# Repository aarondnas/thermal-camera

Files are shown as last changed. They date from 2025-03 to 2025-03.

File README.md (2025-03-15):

# Gesundheitstechnik Gruppenprojekt

In diesem Projekt wird ein Prototyp für einen Thermographen (Wärmebildkamera) entwickelt.

## Inhaltsverzeichnis
1. [Beschreibung](#beschreibung)
2. [Anforderungen an die Entwicklungsumgebung](#anforderungen-an-die-entwicklungsumgebung)
3. [Verwendete Libraries](#verwendete-libraries)
4. [Setup und Installation](#setup-und-installation)
    - [Software](#software)
        - [Installation Raspberry Pi OS](#installation-raspberrypi-os)
        - [Terminal Installationen](#terminal-installationen)
        - [Implementierung von Code aus Repository](#)
    - [Hardware](#hardware)
        - [CAD - Setup und Installation](#cad)
    - [Elektronik](#elektronik)
        - [Bauteile](#bauteile)
5. [Support](#support)

## Beschreibung
Teil des Projekts ist die Entwicklung der Software, der Elektrotechnik und der Konstruktion.

Wichtigste Funktionen:
- Erkennung des zu messenden Körperteils
- ein Körperteil einrahmen und fixieren
- Verschiedene Filtermodi zur Temperaturmessung zwischen 36 und 39° Celsius
- Bedienoberfläche
- Schnappschussfunktion durch digitalen Trigger und Abspeichern des Bildes

## Anforderungen an die Entwicklungsumgebung
[Python 3.x](https://www.python.org/downloads/)

## Verwendete Libraries
- tkinter 
- from tkinter import *
- cv2
- customtkinter
- from operator import mil
- import lumpy as np
- from PIL import Image, ImageDraw, Imagefilter, ImageTK
- datetime

## Verwendete IDE
Visual Studio Code Version: 1.72.1 (Universal)

## Setup und Installation
### Software
#### Installation Raspberry Pi OS auf Micro-SD
Installiere mit dem [Raspberry Pi Imager](https://www.raspberrypi.com/software/) das Betriebssystem für den Raspberry Pi 3b v. 1.2 um anschließend folgende Imports über das Terminal zu installieren.

#### Terminal Installationen:
1. Installieren der Libraries:

Für Ubuntu: 
```
sudo apt-get install python3-tk
sudo apt-get install libopencv-dev
```

#### Implementierung von Code aus Repository
Um den gesamten Code ordnungsgemäß nutzen zu können, downloade [hier](https://gitlab.rz.htw-berlin.de/s0577479/gesundheitstechnik_thermograph/-/archive/main/gesundheitstechnik_thermograph-main.zip) die .zip Datei um ihn anschließend auf dem Raspberry Pi auszuführen. 

### Hardware
#### CAD
Der erste Prototyp für das Gehaeuse wurde mit AutoDesk 360 entworfen. Im Ordner [Gehaeuse](/Gehaeuse) wurden drei unterschiedliche Formate angelegt: .stp, .igs und .f3z. Falls ein anderes Format bevorzugt wird, kann über diesen [Link](https://mygmx81809.autodesk360.com/g/shares/SH9285eQTcf875d3c53958665734c225feb5) das gewünschte Format heruntergeladen werden.

Referenz unseres ersten Prototypen gibt es im Wiki unter dem Reiter Konstruktion.

***

### Elektronik
#### Bauteile
Folgende Bauteile werden für den Nachbau benötigt:<br>
Bildschirm: [Joy-IT 3,5" LCD-Display 480x320 Pixel](https://joy-it.net/de/products/RB-TFT3.5)<br>
Computer: [Raspberry Pi 3B](https://www.berrybase.de/raspberry-pi-3-modell-b)<br>
DC/DC Wandler: [adafruit PowerBoost 1000C](https://www.adafruit.com/product/2465)<br>
Sensoren: [FLIR Lepton Pure Thermal 2](https://groupgets.com/manufacturers/getlab/products/purethermal-2-flir-lepton-smart-i-o-module)
& [MLX 90640](https://www.adafruit.com/product/4407)<br>
Akku: [Eckstein Energy 3,7V 2500mAh](https://eckstein-shop.de/LiPo-Akku-Lithium-Ion-Polymer-Batterie-37V-2500mAh-mit-JST-PHR-2-Stecker-LP785060)<br>
Button: [Unimec MEC Momentary Push Button Switch](https://docs.rs-online.com/af73/A700000008823370.pdf)

## Support
General Support: 
Achim.Klenk@student.htw-berlin.de

Software Support: 
Aaron.Schultz@student.htw-berlin.de / Falko.Kristen@student.htw-berlin.de

CAD Support: 
Arthur.Schneider@student.htw-berlin.de

***

## Autoren
Achim Klenk, 
Falko Kristen, 
Aaron Schultz, 
Arthur Schneider

## Lizenz
For open source projects, say how it is licensed.

## Project status
If you have run out of energy or time for your project, put a note at the top of the README saying that development has slowed down or stopped completely. Someone may choose to fork your project or volunteer to step in as a maintainer or owner, allowing your project to keep going. You can also make an explicit request for maintainers.

↑ [zurück zur Übersicht](#gesundheitstechnik-gruppenprojekt)

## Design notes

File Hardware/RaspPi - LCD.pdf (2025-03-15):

| 3,5 LCD | | Rasp Pi
| 3,3V | 1 | 3,3V
| 5V | 2 | 5V
| NC | 3 | GPIO2 Serial Data (I2C)
| 5V | 4 | 5V
| NC | 5 | GPIO3 Serial Clock (I2C)
| GND | 6 | GND
| NC | 7 | GPIO 4
| NC | 8 | GPIO 14 (UART TX)
| GND | 9 | GND
| NC | 10 | GPIO 15(UART RX)
Touch Interrupt, detektiert Berührung | TP_IRQ | 11 | GPIO 17 Chip Enable-CE1 (SPI1)
| NC | 12 | GPIO 18 Chip Enable_CE0 (SP1) [PWM]
| NC | 13 | GPIO 27
| GND | 14 | GND
| NC | 15 | GPIO 22
| NC | 16 | GPIO 23
| 3,3V | 17 | 3,3V
Instruction/Data Register Selection | LCD_RS | 18 | GPIO 24 | ? Interaktionspin
SPI data input of LCD/Touch Panel | LCD_SI/TP_SI | 19 | GPIO 10 MOSI (SPI 0)
| GND | 20 | GND
SPI data output of Touch Panel | TP_SO | 21 | GPIO 09 MISO (SPI 0)
Reset | RST | 22 | GPIO 25 | ? Interaktionspin
SPI Clock of LCD/Touch Panel | LCD_SCK/TP_SCK | 23 | GPIO 11 SCLK (SPI 0) | Clock
LCD chip selection, low active | LCD_CS | 24 | GPIO 8 Chip Enable-CE0 (SPI0) | ? Interaktionspin
| GND | 25 | GND
Touch Panel chip selection, low active | TP_CS | 26 | GPIO 7 Chip Enable-CE1 (SPI0) | ? Interaktionspin

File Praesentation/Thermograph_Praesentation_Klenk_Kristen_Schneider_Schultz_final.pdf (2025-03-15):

## Projekt Gesundheitstechnik

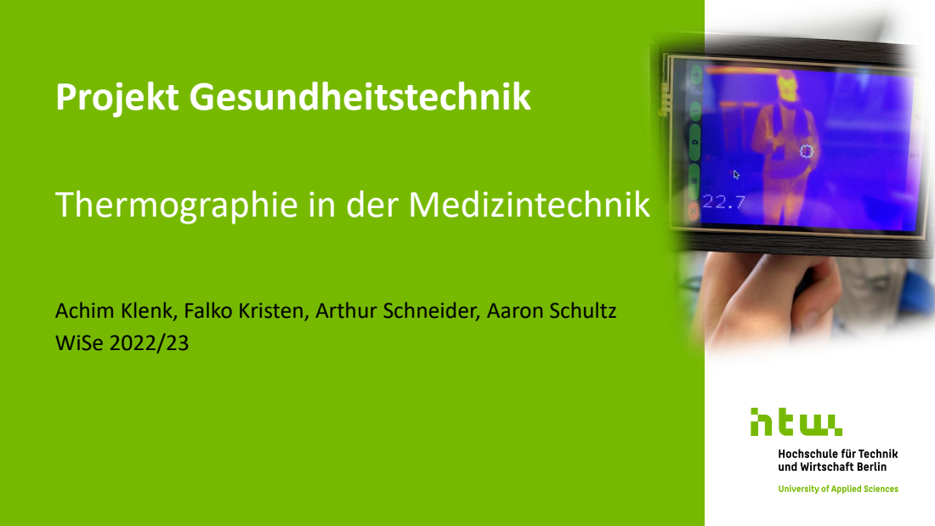
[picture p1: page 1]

Thermographie in der Medizintechnik

Achim Klenk, Falko Kristen, Arthur Schneider, Aaron Schultz
WiSe 2022/23

- Konzeptidee
- Einsatzgebiete
- Aufbau und Funktionsweise
- Konstruktion
- Elektronik
- Software
- Demonstration
- Projektverlauf und Vision

## Inhaltsverzeichnis

2

- Thermographie – die Wärmebildkamera
- Handheld Device für
- klinische Anwendungen
- Großveranstaltungen
- Eindämmung Corona-Pandemie

## Konzeptidee

3

## Marktanalyse

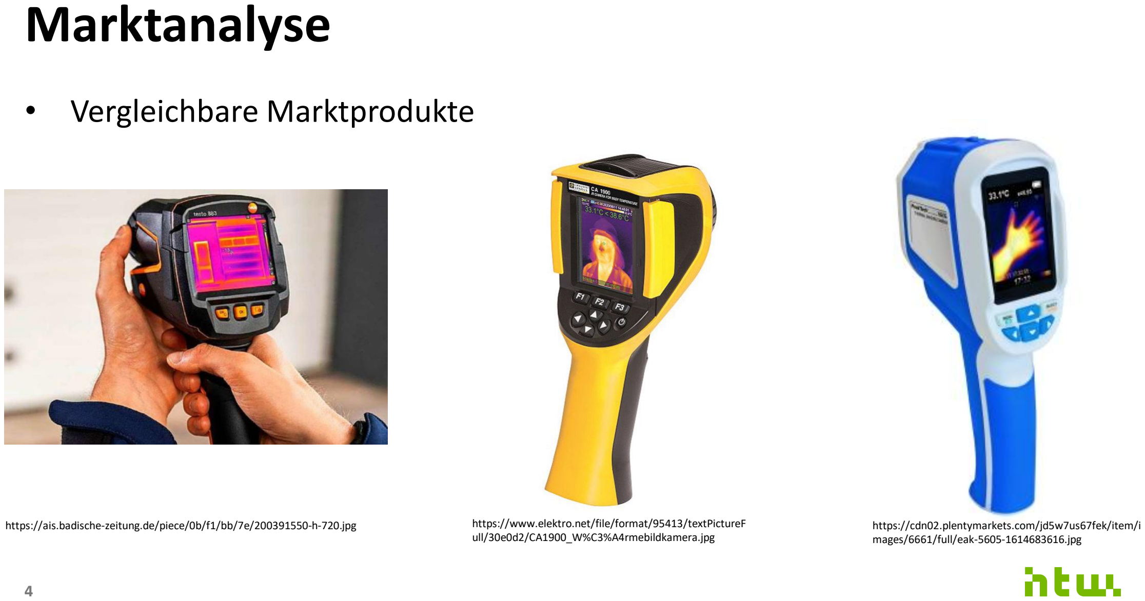
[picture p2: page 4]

- Vergleichbare Marktprodukte

4

https://ais.badische-zeitung.de/piece/0b/f1/bb/7e/200391550-h-720.jpg | https://www.elektro.net/file/format/95413/textPictureF ull/30e0d2/CA1900_W%C3%A4rmebildkamera.jpg
https://cdn02.plentymarkets.com/jd5w7us67fek/item/images/6661/full/eak-5605-1614683616.jpg

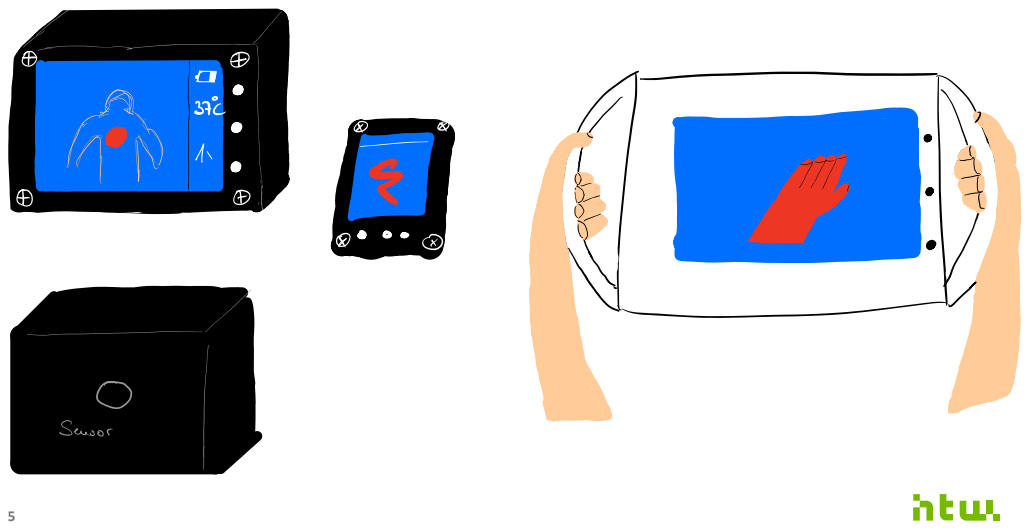
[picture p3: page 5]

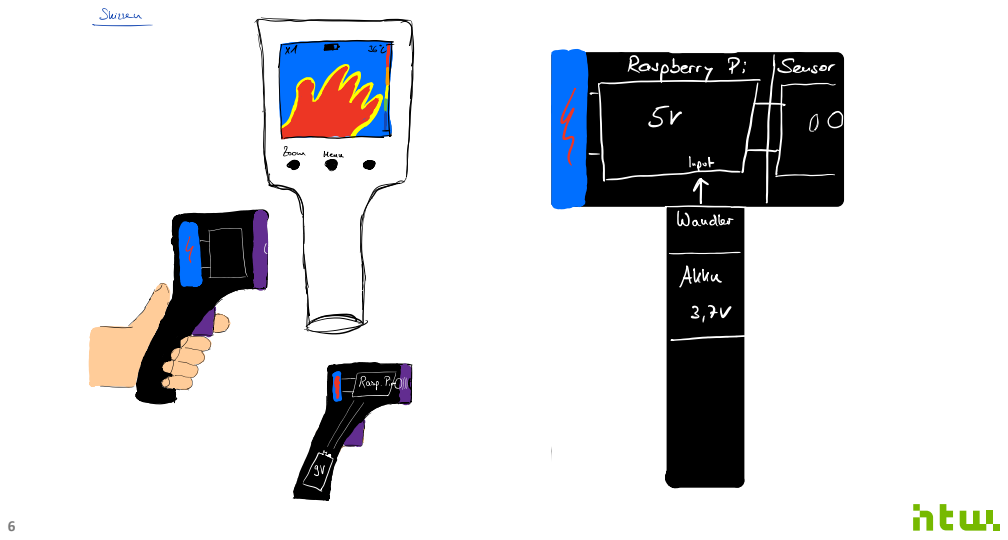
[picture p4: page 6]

- Anforderungen
- Dimension eines Handhelds
- Modulares, ergonomisches Design
- Beide Sensoren sollen verbaut sein
- Physischer Button

## Aufbau und Funktionsweise - Konstruktion

7

- Bauteilrecherche (Größe der einzelnen Bauteile)
- Konzept über Platzierung der Bauteile im Gehäuse
- ungefähre Dimensionen des Gerätes festlegen
- Positionierung und Funktionsweise des Buttons bestimmen

## Vorbereitung für Konstruktion

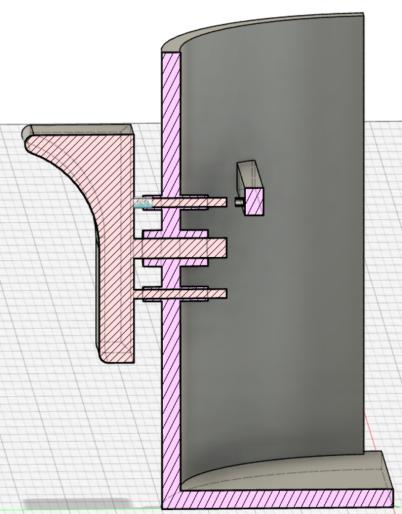
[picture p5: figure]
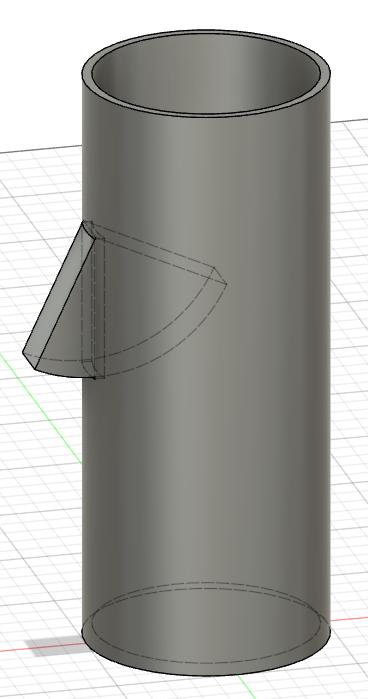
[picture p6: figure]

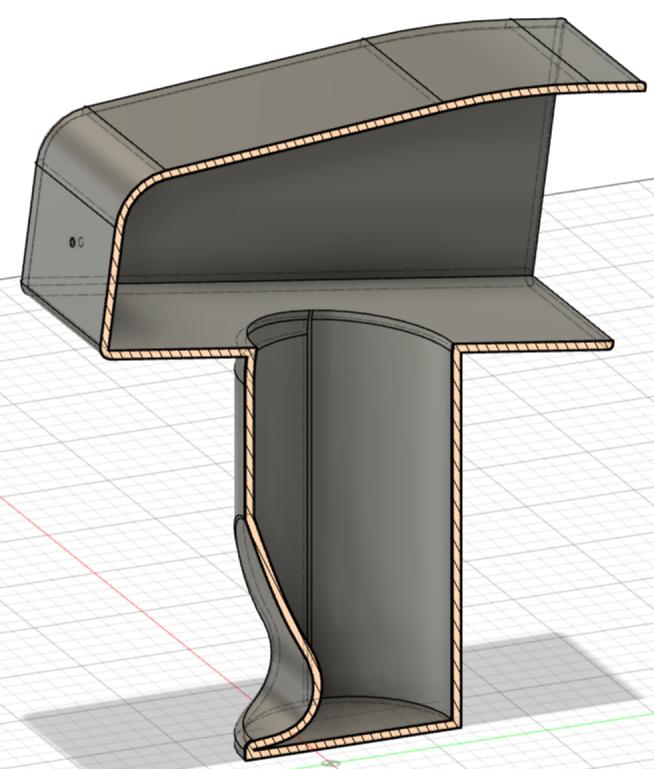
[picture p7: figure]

- Entstanden ohne jegliche Hilfe
- Zwei – Hälften – Design
- Ergonomie und Ästhetik im Vordergrund

## Erste Konstruktionsidee v.0

- Wahl der Sensoren
- Kabelloses Gerät
- Zwei Budget Modelle der Infrarot Sensoren

## Aufbau und Funktionsweise - Hardware

10

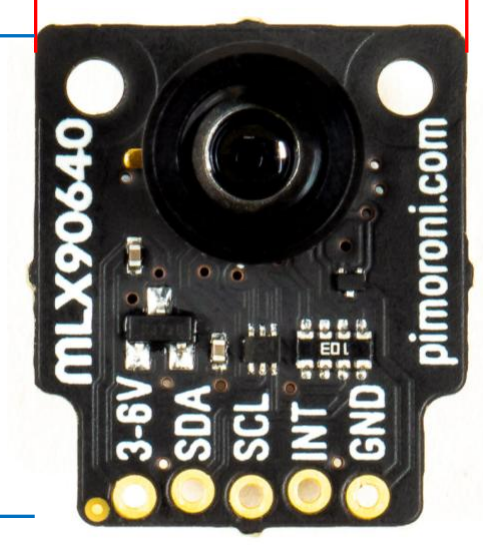
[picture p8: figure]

MLX 90640 (32 x 24
Pixel)
Low budget | High budget

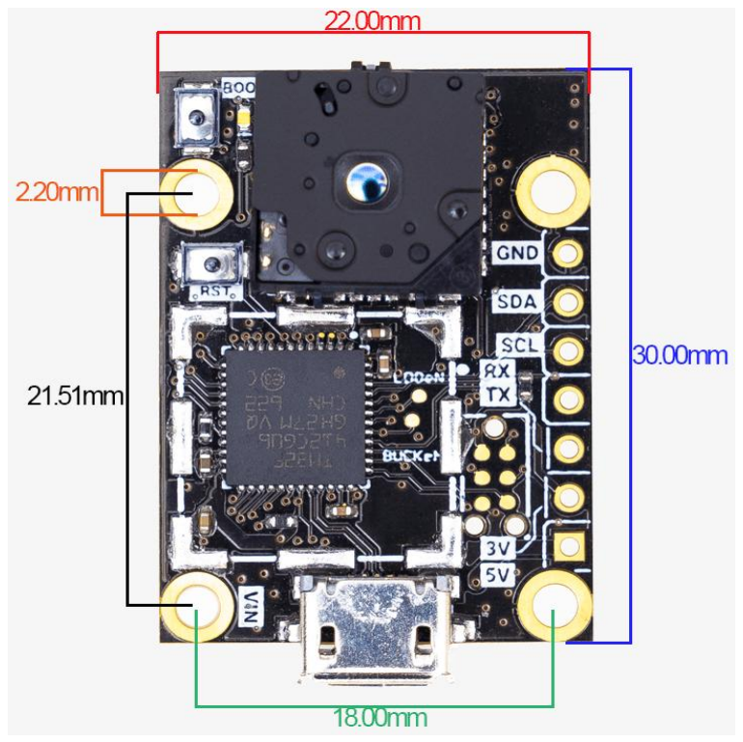
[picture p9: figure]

FLIR Lepton 3.5 (160 x 120 Pixel)

19.00mm

22.00mm

https://cdn.shopify.com/s/files/1/0174/1800/products/mlx90640-2_1500x1500.jpg?v=1656081430 | https://groupgets.com/manufacturers/getlab/products/purethermal-2-flir-lepton-smart-i-o-module

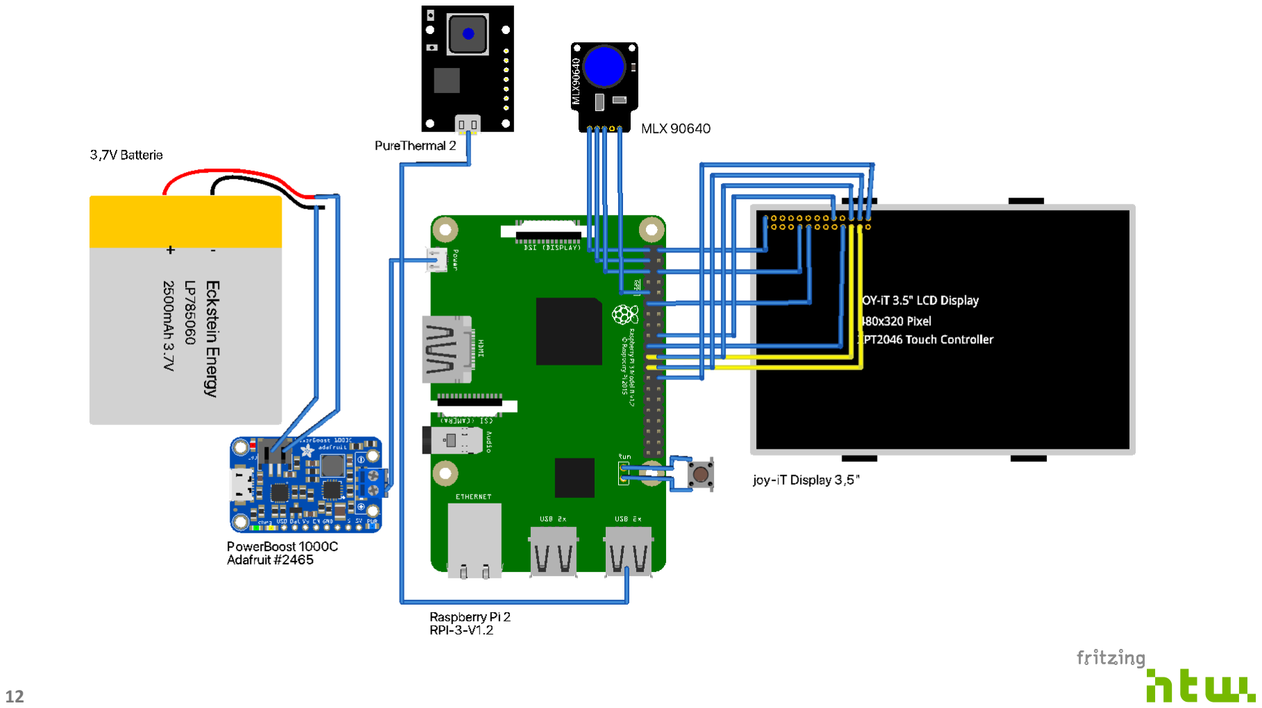
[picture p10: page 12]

12

# GUI (Graphical User Interface)

13

- Sprache: Python
- Ausführbar auf:
- Raspberry Pi (Linux) mit FLIR Lepton 3.5
- 160 x 120 Pixel
- Raspberry Pi (Linux) mit MLX 90640
- 32 x 24 Pixel
- Windows mit Webcam
- Mac OS mit Webcam

## Voraussetzungen

14

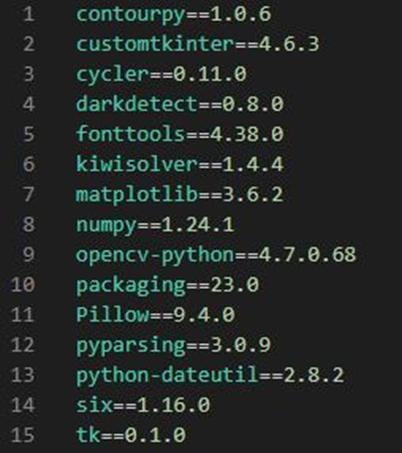
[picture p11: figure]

- Sprache: Python
- Ausführbar auf:
- Raspberry Pi (Linux) mit FLIR Lepton 3.5
- 160 x 120 Pixel
- Raspberry Pi (Linux) mit MLX 90640
- 32 x 24 Pixel
- Windows mit Webcam
- Mac OS mit Webcam

## Voraussetzungen

15

Bibliotheken:

## CustomTKinter by Tom Schimansky

16

- Automatische Sensorerkennung
- Modi: Map Modus, Fieber Modus, Visier Modus
- Modus Info
- Screenshot
- Freeze Funktion
- 2x Zoom
- Live Min-, Mid-, Max-Temperatur mit Seitenleiste
- Colormaps (openCV) - Bone, Turbo, Plasma, Hot, Cool
- Fotogalerie - Ansicht, Scrollen, Löschen
- Abschaltfunktion

## Funktionen & Features (GUI)

17

## Überblick

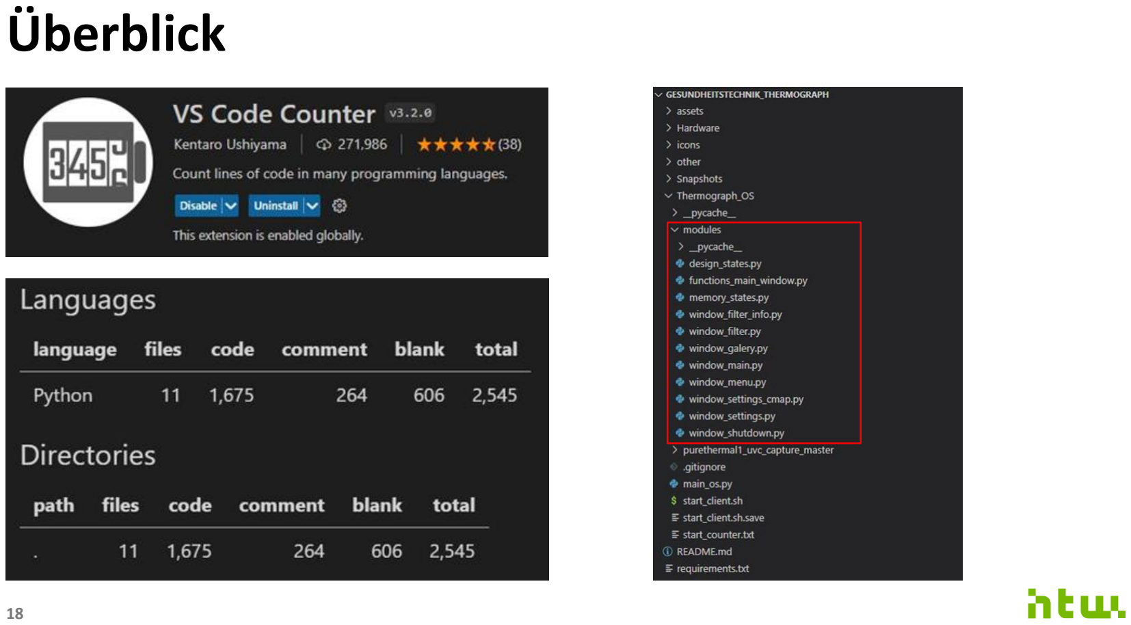
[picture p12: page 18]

18

- Fenster:
- Main
- Shutdown
- Menu
- Modi (Filter)
- Modus Info
- Gallery
- Settings
- Heatmap Settings

## Aufbau

19

- Speicherklassen:
- Memory States (Setup)
- Design States
- Funktionsklassen:
- Functions

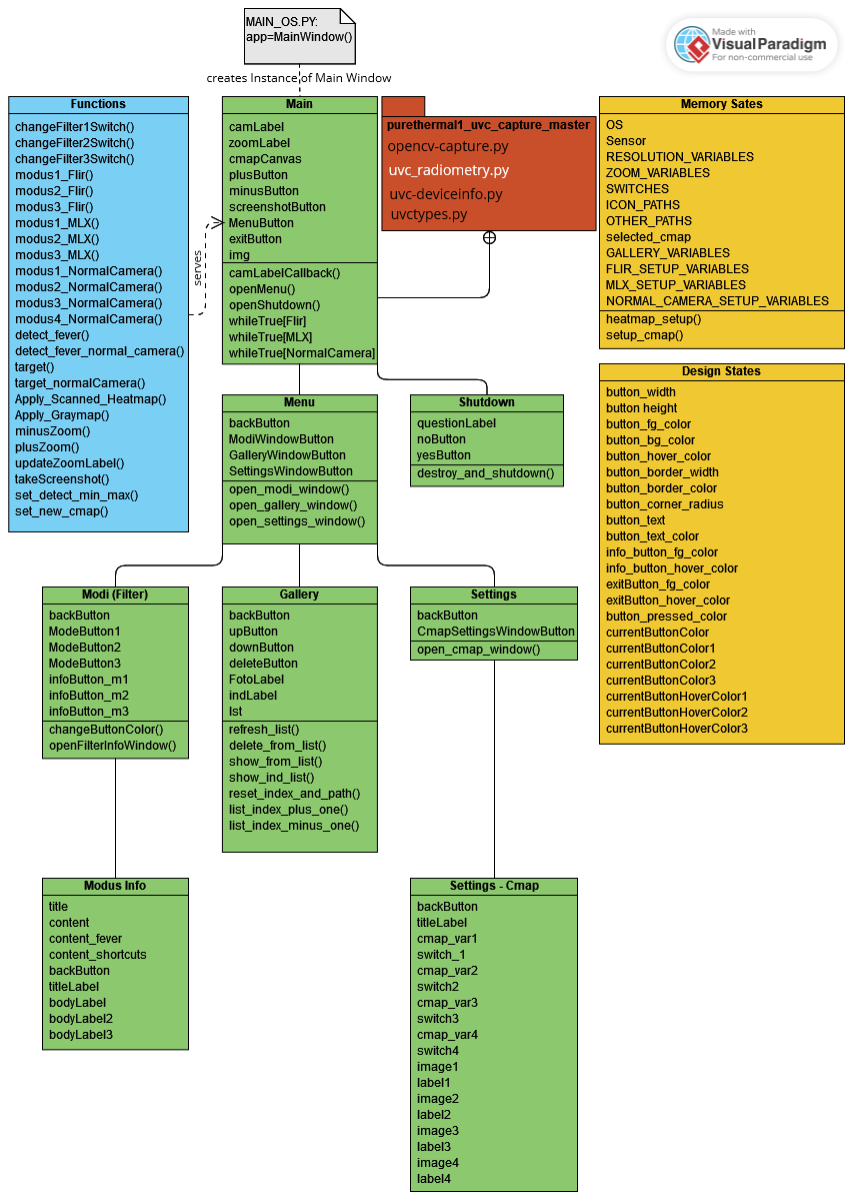
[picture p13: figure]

20

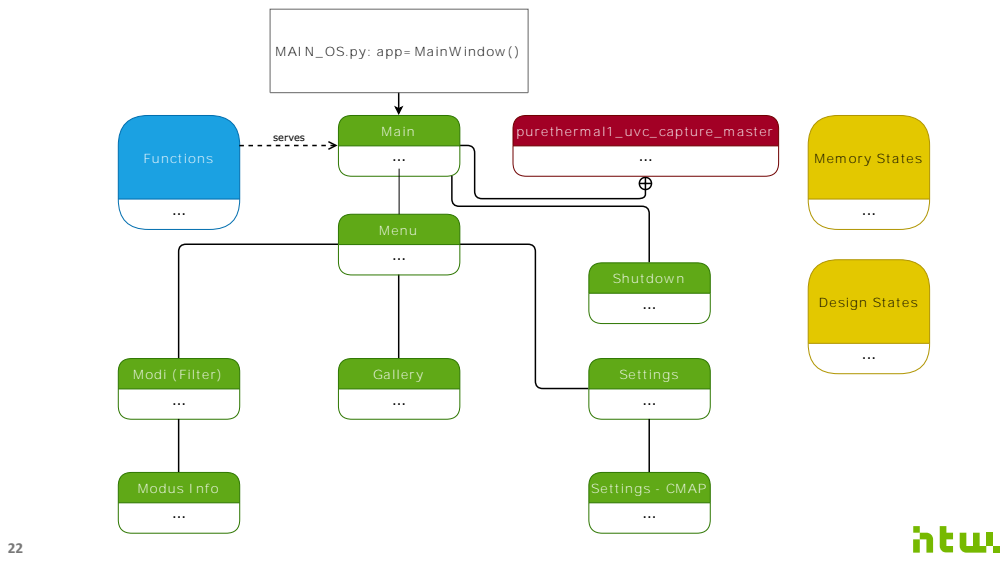
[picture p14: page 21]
Functions; Main; puretherm al1 _ uvc_ capture_ m aster; Mem ory States; Design States; Menu; Shutdow n; Settings; Gallery; Modi ( Filter); Modus I nfo; Settings - CMAP; serves

MAI N_ OS.py: app= MainW indow ( )

## Aufbau von Main Fenster

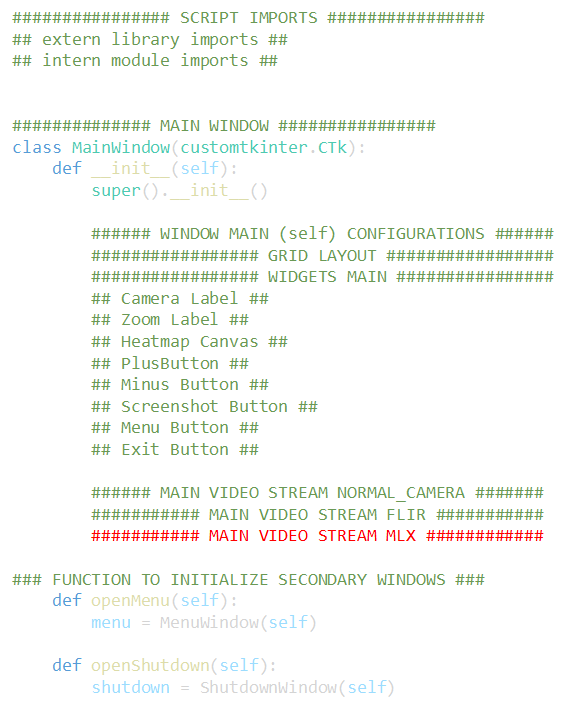
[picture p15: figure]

23

- Raspberry Pi
OS 32-Bit

## Betriebssystem

27

https://cdn.xingosoftware.com/elektor/images/fetch/dpr_1/https%3A%2F %2Fwww.elektormagazine.de%2Fassets%2Fupload%2Fimages%2F11%2F20 180327115958_raspbian-logo.png

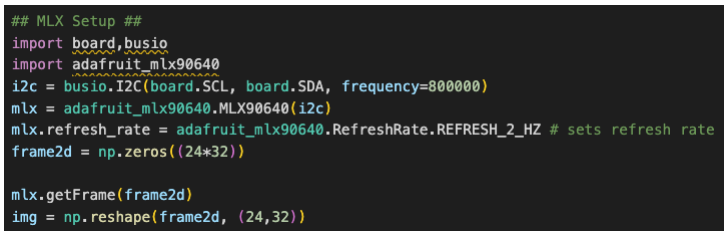
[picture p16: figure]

- Sensor MLX 90640
- Schnittstelle: I2C
- Bibliothek: adafruit_mlx90640

## Sensorimplementierung

28

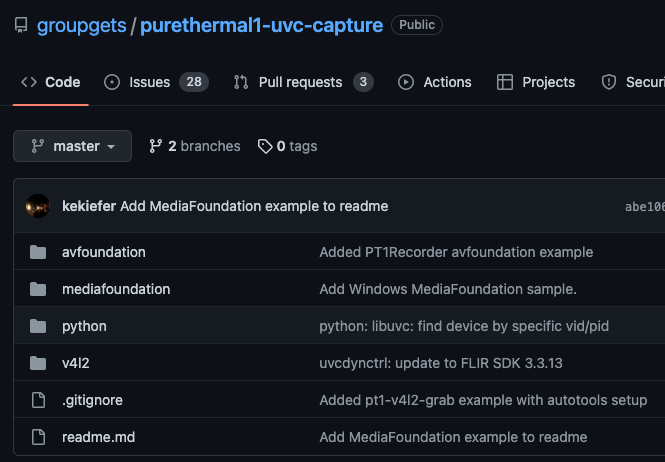
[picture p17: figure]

- Sensor Flir Pure Thermal 2
- Schnittstelle: Micro-USB
- Bibliothek: uvctypes, openCV

- Austausch von Daten
zwischen mehreren
Programmen
- Socket besteht aus Client (Sender) und Server
(Empfänger)
- separate Terminals, um py-Dateien simultan auszuführen

## Socketstream

29

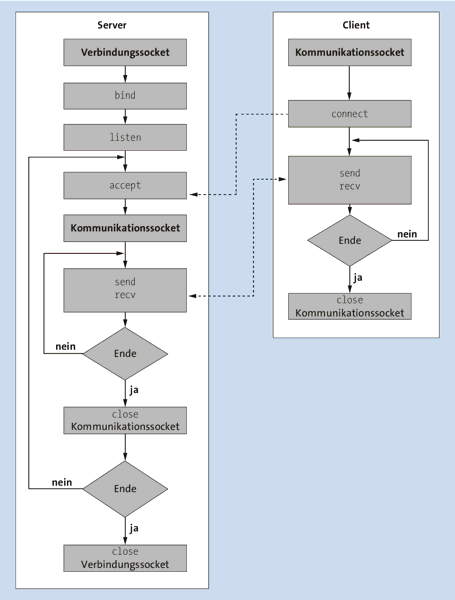
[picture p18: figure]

https://openbook.rheinwerk-verlag.de/python/bilder/client-server.png

- Textdatei mit Endung „.sh“
- Genutzt, um Befehle und Kommandos auszuführen
- Stream Rohdaten Flir Sensor
- Zweitterminal Gnome

## BASH - Skript

30

- .desktop Datei
- Start der GUI bei Bootup des Raspberry Pi‘s

## Autostart

31

- Pseudokolorierung anhand der ausgelesenen Temperaturwerte

## Funktion Heatmap

33

## Funktion Fiebererkennung

34

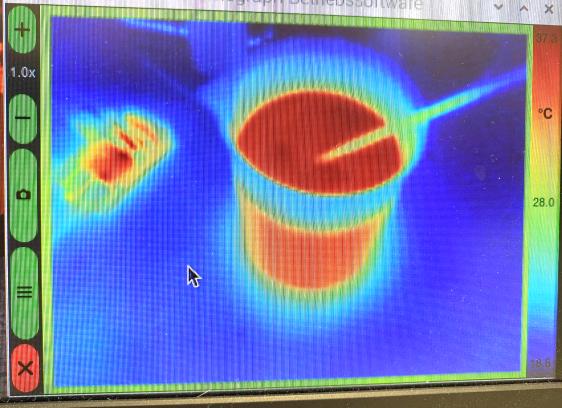
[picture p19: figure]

36,5°C - 37,4°C: | Normal-Temperatur
37,5°C - 38,0°C: | Subfebrile Temperatur
38,1°C - 38,5°C: | Leichtes Fieber

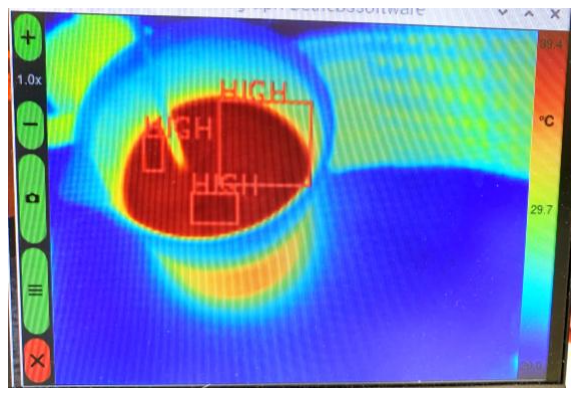
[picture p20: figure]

38,6°C - 39,0°C: | Mäßiges Fieber
39,1°C - 39,9°C: | Hohes Fieber
40,0°C - 42,0°C: | Sehr hohes Fieber
> 42,0°C | Tödlich

https://www.internisten-im-netz.de/krankheiten/fieber/temperatur-regulation-imkoerper.html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,9%C2%B0C%3A%20Hohes%20Fieber

## Fiebererkennung

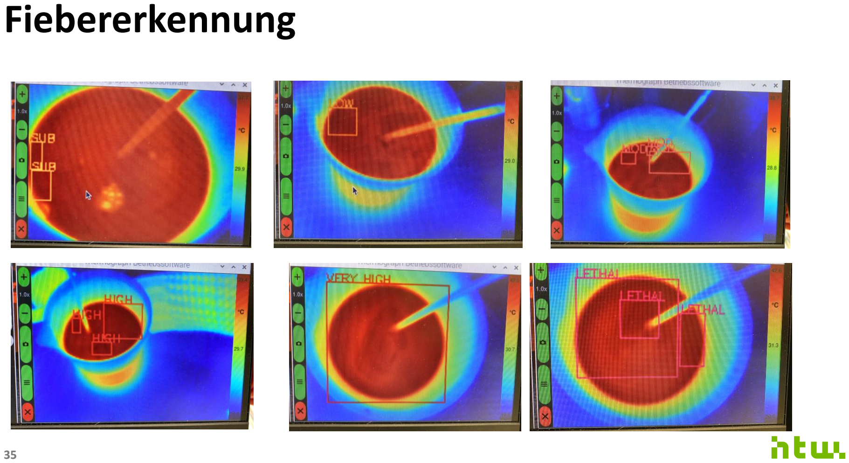
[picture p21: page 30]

35

- Mittelpunkt des Bildes ist Temperaturmesspunkt

## Funktion Target

36

## Zuverlässigkeit Messungen

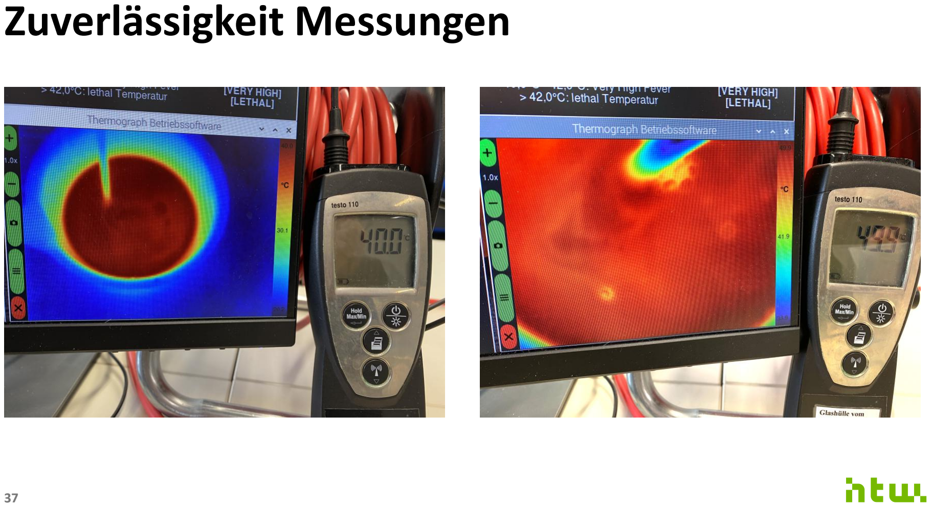
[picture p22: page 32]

37

# Demonstration

38

- Anfänge
- Organisation
- Aufgabenaufteilung
- Misserfolge
- Sensoren
- Rohdaten
- Heatmap
- Fehlendes Konstruktionswissen

## Projektverlauf

39

- Display mit HDMI Anschluss
- Gehäuseverbesserung
- Programmierung in C/C++
- Usability
- Akkustand
- Spracheinstellung
- Lautsprecher für akustische Signale
- Sensorwechsel per Einstellungen
- Farbeinstellungen

## Vision

40

- https://ais.badische-zeitung.de/piece/0b/f1/bb/7e/200391550-h-720.jpg
- https://www.elektro.net/file/format/95413/textPictureFull/30e0d2/CA1900_W%C3%A4rmebildkamera.jpg
- https://cdn02.plentymarkets.com/jd5w7us67fek/item/images/6661/full/eak-5605-1614683616.jpg
- https://cdn.shopify.com/s/files/1/0174/1800/products/mlx90640-2_1500x1500.jpg?v=1656081430
- https://groupgets.com/manufacturers/getlab/products/purethermal-2-flir-lepton-smart-i-o-module
- https://openbook.rheinwerk-verlag.de/python/bilder/client-server.png
- https://cdn.xingosoftware.com/elektor/images/fetch/dpr_1/https%3A%2F%2Fwww.elektormagazine.de%2Fassets%2Fupload%2Fimages%2F11%2F20180327115958_raspbian-logo.png (https://cdn.xingosoftware.com/elektor/images/fetch/dpr_1/https%3A%2F%2Fwww.elektormagazine.de%2Fassets%2Fupload%2Fimages%2F11%2F20180327115958_raspbian-logo.png)
- https://staging-assets.raspberrypi.com/static/md-bfd602be71b2c1099b91877aed3b41f0.png
- https://app.diagrams.net/
- https://online.visual-paradigm.com/de/
- https://www.ernstlx.com/linux90script.html
- https://www.makeuseof.com/how-to-run-a-raspberry-pi-program-script-at-startup/
- https://realpython.com/python-sockets/
- https://www.autodesk.de/products/fusion-360/overview?term=1-YEAR&tab=subscription
- https://www.internisten-im-netz.de/krankheiten/fieber/temperatur-regulation-imkoerper.html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,9%C2%B0C%3A%20Hohes%20Fieber (https://www.internisten-im-netz.de/krankheiten/fieber/temperatur-regulation-im-koerper.html)
- https://account.htw-berlin.de/htwfont/index
- https://corporatedesign.htw-berlin.de/musterdokumente/powerpoint-vorlagen/

## Quellenverzeichnis

41

Vielen Dank.

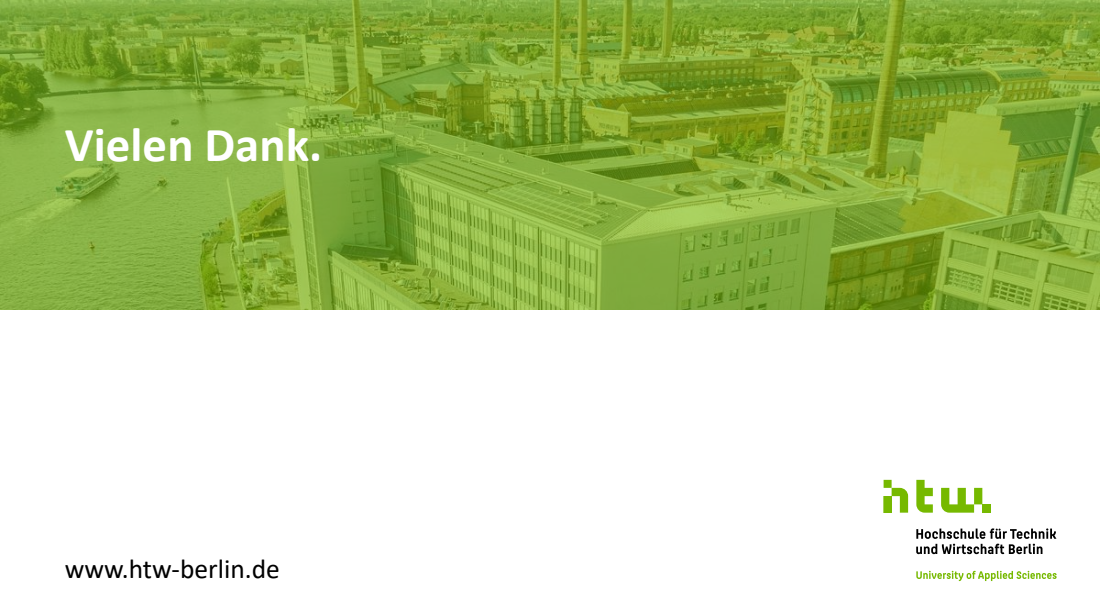
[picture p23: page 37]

www.htw-berlin.de

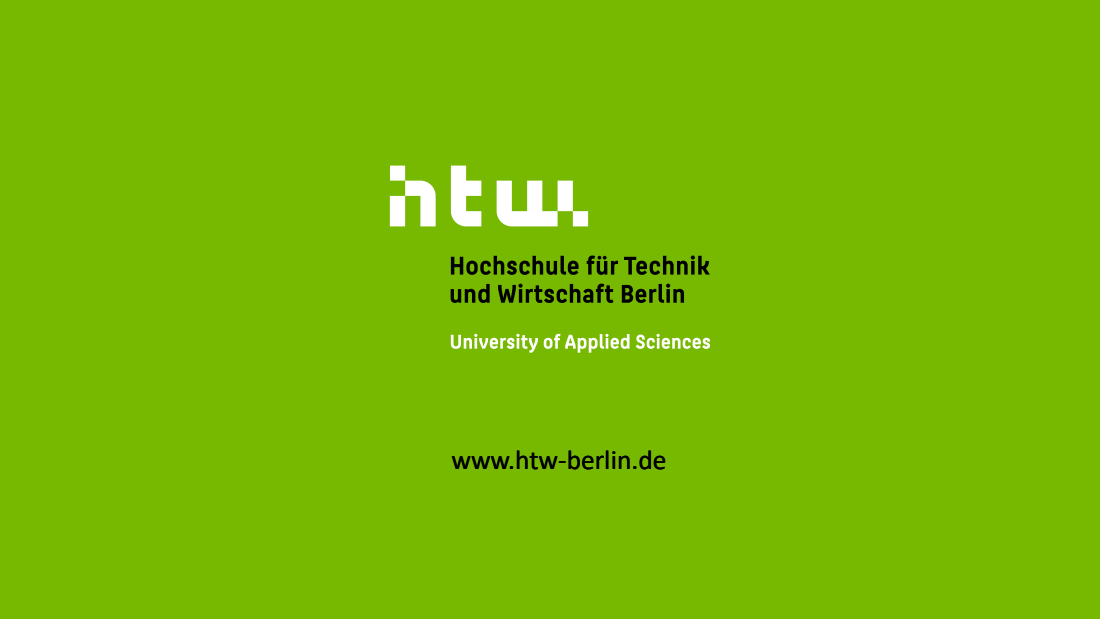
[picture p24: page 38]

www.htw-berlin.de

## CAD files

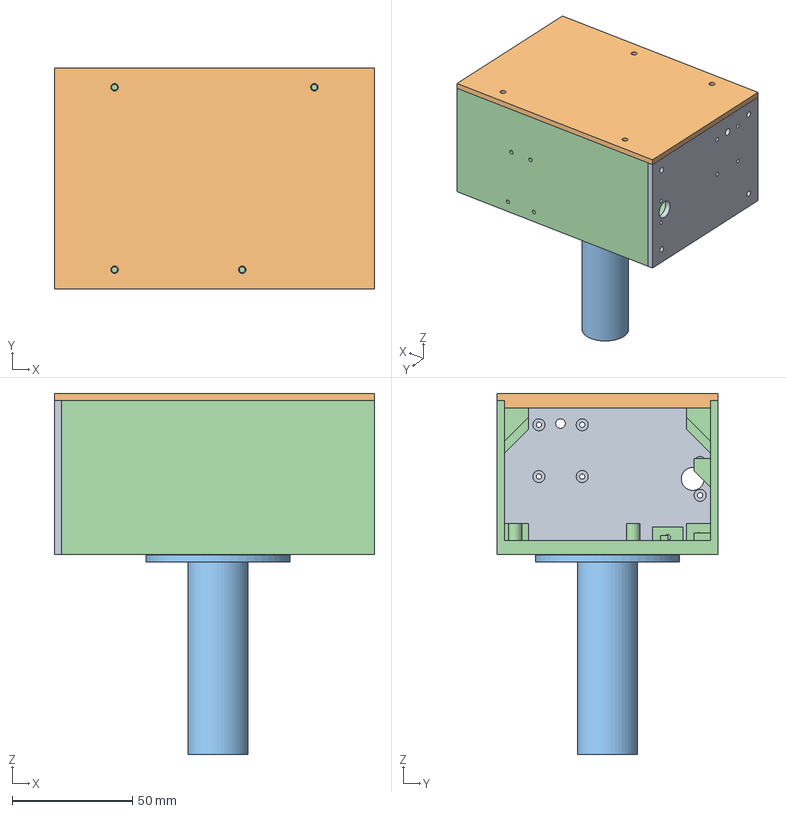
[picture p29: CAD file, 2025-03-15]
Gehaeuse/Thermograph.stp
133.0 x 91.8 x 150.0 mm
Front.H
Deckel.H
Griff

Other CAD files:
Gehaeuse/Thermograph.f3z
Gehaeuse/Thermograph.igs

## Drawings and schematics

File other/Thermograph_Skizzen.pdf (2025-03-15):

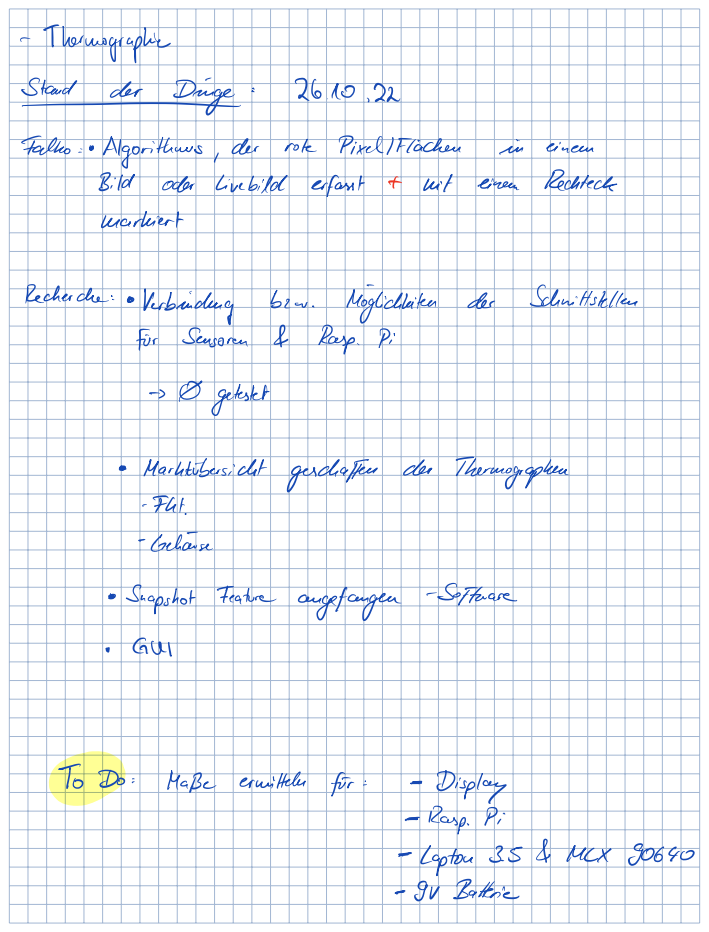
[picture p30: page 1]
Thermographie; Falko; Algorithmus; der; rote; Pixel Flächen; einem; markiert; 0 getestet; Snapshot Feature; angefangen; Software; Gal; Lapton 3.5; Max; Batterie

Recherche | | Verbindung | | bzw | | Möglichkeiten | | der | Schnittstellen

für | | Sensoren | | Rasp | | Pi

Marktübersicht geschaffen | der | Thermographen
Fat
schön

To | Do | Maße | ermitteln | für | Display

Rasp | Pi

weiße | Kiste | 433

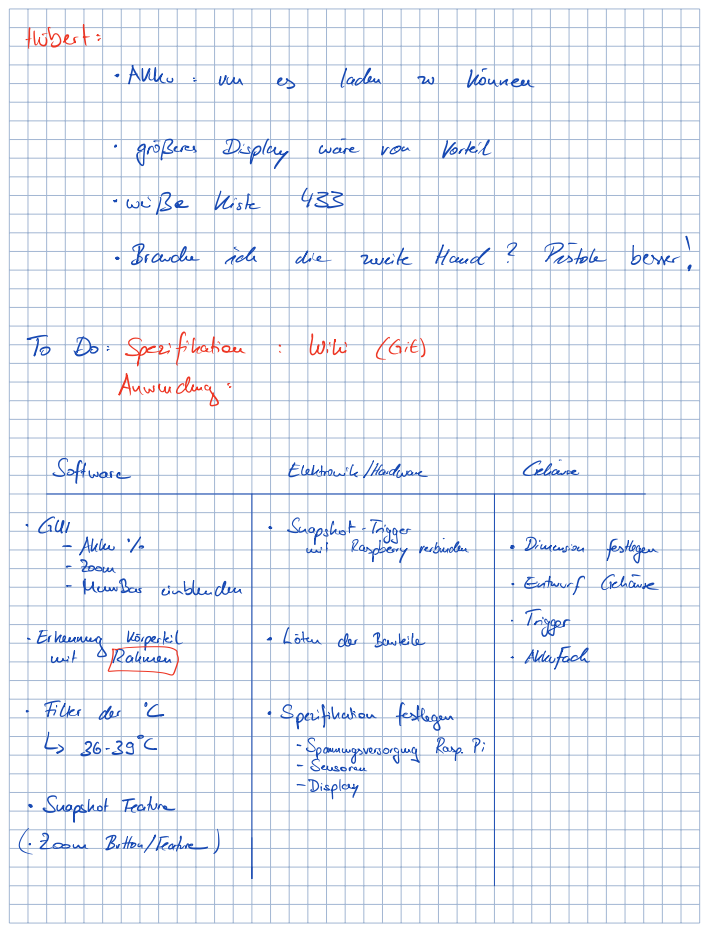
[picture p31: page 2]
größeres; Display; wäre; von; Vorteil; Brauche; ich; die; zweite; Hand; Pistole; besser; Spezifikation; Wiki; Git; Anwendung; Software; Elektronik Hardware; Gehöre; Erkennung; Körperteil; Löten; der; Bauteile

Hubert

Akku | um | es | laden | zu | können

Gut | | | | | Snapshot | Trigger
Akku
Zoom | | | | PM | den | Dimension | festlegen
MunBar | | einblenden | | | | Entwurf | Gehäuse

Trigger

mit | | Rahul | | | | | Akkfach

Filter der | | | C | Spezifikation | festlegen
36 | 394

Snapshot Feature
Zoom Button Feature

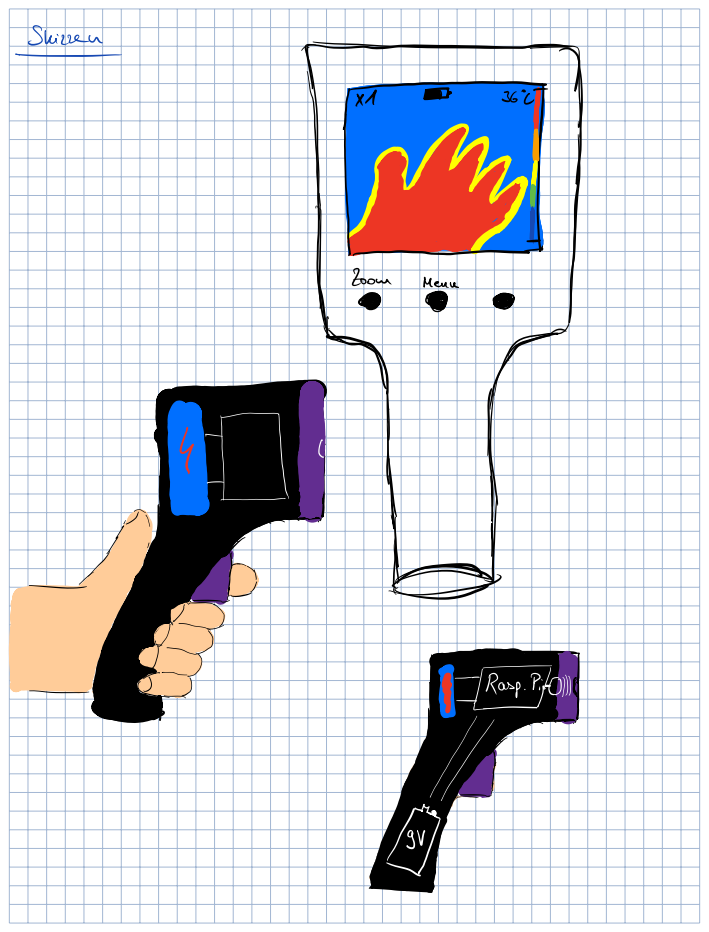
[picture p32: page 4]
TiniIii; iii; ätzen; jssitssEET

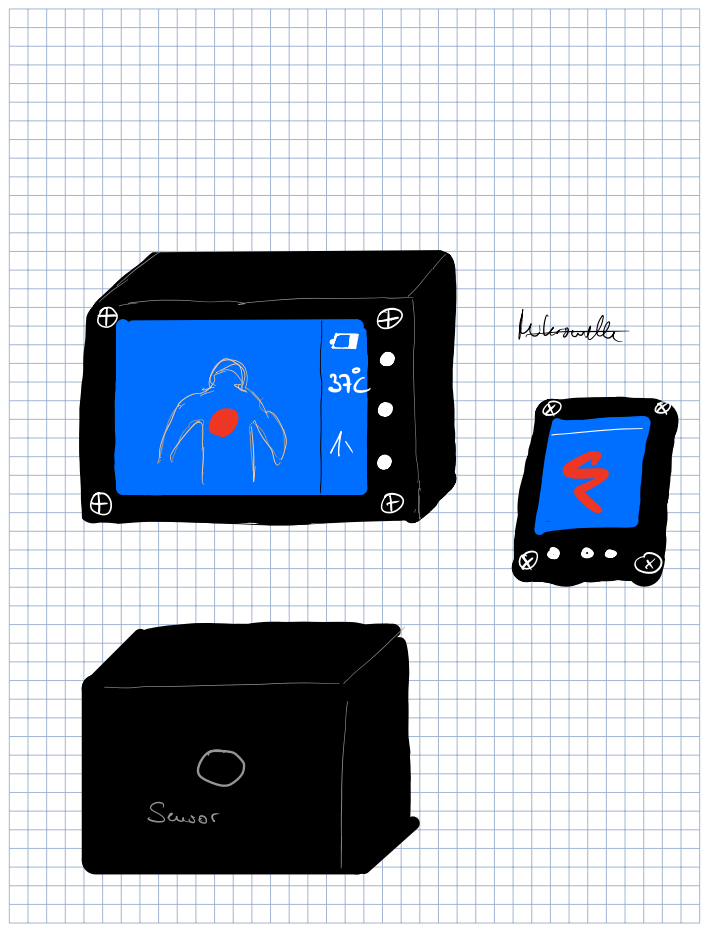
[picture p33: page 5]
tEeriIII; äße

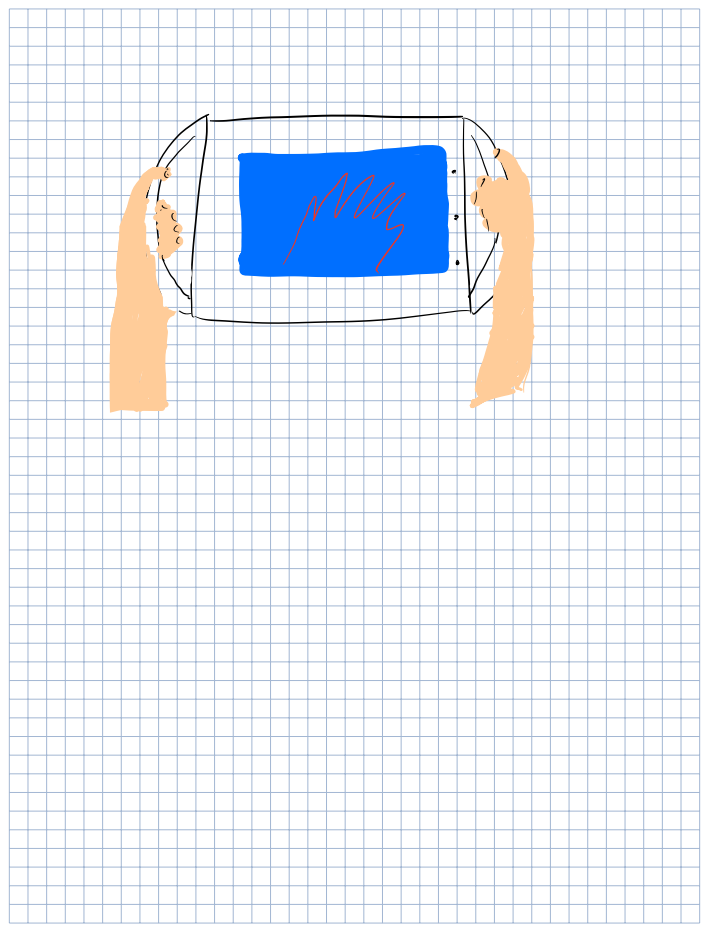
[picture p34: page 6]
jiFi.ie

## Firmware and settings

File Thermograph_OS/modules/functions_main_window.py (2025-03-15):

#-------------------------------------------------------------------#
################ Source Code written by Aaron Schultz ###############
##################### Co-Writer: Falko Kristen ######################
####### All Rights Reserved, Copyright (c) 2023 Aaron Schultz #######
#-------------------------------------------------------------------#

################ SCRIPT IMPORTS ################

## extrern library imports ##
from operator import mul
import datetime
import cv2
import numpy as np
from PIL import Image, ImageTk
import os

## intern module imports ##
from modules.memory_states import MemoryStates as ms




################ FUNCTIONS OF MAIN WNDOW ################

class FunctionsMainWindow:
    

    ## Switch Functions ##

    def changeFilter1Switch():
        if ms.filter1Switch == False:
            ms.filter1Switch = True
            ms.filter2Switch = False
            ms.filter3Switch = False
            ms.filter4Switch = False
        else: ms.filter1Switch = True
    
    def changeFilter2Switch():
        if ms.filter2Switch == False:
            ms.filter1Switch = False
            ms.filter2Switch = True
            ms.filter3Switch = False
            ms.filter4Switch = False
        else: ms.filter2Switch = True

    def changeFilter3Switch():
        if ms.filter3Switch == False:
            ms.filter1Switch = False
            ms.filter2Switch = False
            ms.filter3Switch = True
            ms.filter4Switch = False
        else: ms.filter3Switch = True

    def changeFilter4Switch():
        if ms.filter4Switch == False:
            ms.filter1Switch = False
            ms.filter2Switch = False
            ms.filter3Switch = False
            ms.filter4Switch = True
        else: ms.filter4Switch = True

    def changeScreenshotSwitch():
        if ms.screenshotSwitch == False:
            ms.screenshotSwitch = True
        else: ms.screenshotSwitch = False




    ############################# 
    ### FILTER FUNCTIONS FLIR ###
    #############################


    ## Filter 1 ##

    def filter1_Flir(img,cmapCanvas,MaximumCanvas,MiddleCanvas,MinimumCanvas):
        # sets current min and max values to canvas
        img_colorbar = (img-27315)/100.0 # milli kelvin to °C
        FunctionsMainWindow.set_detected_min_max(img_colorbar,cmapCanvas,MaximumCanvas,MiddleCanvas,MinimumCanvas)
        
        img = (img-27315)/100.0 # milli kelvin to °C
        cv2.normalize(img, img, 0, 255, cv2.NORM_MINMAX)
        
        output = np.copy(img)
        output = np.uint8(output)
        output = cv2.applyColorMap(output, ms.current_cv2_colormap)
        output = cv2.cvtColor(output, cv2.COLOR_BGR2RGB)
        return output


    ## Filter 2 ##

    def filter2_Flir(img,cmapCanvas,MaximumCanvas,MiddleCanvas,MinimumCanvas):
        
        # sets current min and max values to canvas
        img_colorbar = (img-27315)/100.0 # milli kelvin to °C
        FunctionsMainWindow.set_detected_min_max(img_colorbar,cmapCanvas,MaximumCanvas,MiddleCanvas,MinimumCanvas)
        
        # applies cmap with detection
        output = FunctionsMainWindow.detect_fever(img)
        return output
    

    ## Filter 3 ##

    def filter3_Flir(img,cmapCanvas,MaximumCanvas,MiddleCanvas,MinimumCanvas):
        
        # sets current min and max values to canvas
        img_colorbar = (img-27315)/100.0 # milli kelvin to °C
        FunctionsMainWindow.set_detected_min_max(img_colorbar,cmapCanvas,MaximumCanvas,MiddleCanvas,MinimumCanvas)
        
        img = (img-27315)/100.0 # milli kelvin to °C
        output = FunctionsMainWindow.target(img)
        return output
    

    ## Filter 4 ##

    def filter4_Flir(img):
        output = img.copy()
        return output
    




    ############################# 
    ### FILTER FUNCTIONS MLX ###
    #############################

    ## Filter 1 ##
    def filter1_MLX(img,cmapCanvas,MaximumCanvas,MiddleCanvas,MinimumCanvas):
        # sets current min and max values to canvas
        FunctionsMainWindow.set_detected_min_max(img,cmapCanvas,MaximumCanvas,MiddleCanvas,MinimumCanvas)
        
        output = img.copy()
        output = FunctionsMainWindow.Apply_Scanned_Heatmap(output, ms.blank_rgb, ms.width, ms.height, ms.heatMap_array)
        return output

    ## Filter 2 ##
    def filter2_MLX(img,cmapCanvas,MaximumCanvas,MiddleCanvas,MinimumCanvas):
        # sets current min and max values to canvas
        FunctionsMainWindow.set_detected_min_max(img,cmapCanvas,MaximumCanvas,MiddleCanvas,MinimumCanvas)
        
        img_cel = np.copy(img)
        img_raw = np.copy(img_cel)
        
        
        output = img.copy()
        heatmapped_img = FunctionsMainWindow.Apply_Scanned_Heatmap(output, ms.blank_rgb, ms.width, ms.height, ms.heatMap_array)
                    
        if (cv2.inRange(img_cel,0.1,37.4).any() == True):
            mask = cv2.inRange(img_cel,37.5,38.0)
            fever_type = ""

        if (cv2.inRange(img_cel,37.5,38.0).any() == True):
            mask = cv2.inRange(img_cel,37.5,38.0)
            fever_type = "SUBFEBRIL"
            
        if (cv2.inRange(img_cel,38.1,38.5).any() == True):
            mask = cv2.inRange(img_cel,38.1,38.5)
            fever_type = "LOW"
            
        if (cv2.inRange(img_cel,38.5,39.0).any() == True):
            mask = cv2.inRange(img_cel,38.5,39.0)
            fever_type = "MODERATE"

        if (cv2.inRange(img_cel,39.1,39.9).any() == True):
            mask = cv2.inRange(img_cel,39.1,39.9)
            fever_type = "HIGH"   
            
        if (cv2.inRange(img_cel,40.0,42.0).any() == True):
            mask = cv2.inRange(img_cel,40.0,42.0)
            fever_type = "VERY HIGH"
            
        kernal = np.ones((5,5),"uint8")
        mask = cv2.dilate(mask,kernal)
        contours,hierarchy = cv2.findContours(mask,cv2.RETR_TREE,cv2.CHAIN_APPROX_SIMPLE)
        
        for pic, contour in enumerate(contours):
            area = cv2.contourArea(contour)
            if area > 30:
                x,y,w,h = cv2.boundingRect(contour)
                heatmapped_img = cv2.rectangle(heatmapped_img,(x,y),(x+w,y+h),(255,255,255),1)
                cv2.putText(heatmapped_img, f"{fever_type}", (x,y),cv2.FONT_HERSHEY_SIMPLEX,0.2,(255,255,255))

        return heatmapped_img
        

    ## Filter 3 ##

    def filter3_MLX(img):
        output = FunctionsMainWindow.target(img)
        return output


    ## Filter 4 ##

    def filter4_MLX(img):
        output = img.copy()
        return output




    ###################################### 
    ### FILTER FUNCTIONS NORMAL CAMERA ###
    ######################################


    ## Filter 1 ##

    def filter1_NormalCamera(img,cmapCanvas,MaximumCanvas,MiddleCanvas,MinimumCanvas):
        FunctionsMainWindow.set_detected_min_max(img,cmapCanvas,MaximumCanvas,MiddleCanvas,MinimumCanvas)
        output = img.copy()
        output = np.uint8(output)
        output = cv2.applyColorMap(output, ms.current_cv2_colormap)
        output = cv2.cvtColor(output, cv2.COLOR_BGR2RGB)
        return output


    ## Filter 2 ##

    def filter2_NormalCamera(img,cmapCanvas,MaximumCanvas,MiddleCanvas,MinimumCanvas):
        FunctionsMainWindow.set_detected_min_max(img,cmapCanvas,MaximumCanvas,MiddleCanvas,MinimumCanvas)
        output = img.copy()
        output = np.uint8(output)
        output = cv2.applyColorMap(output, ms.current_cv2_colormap)
        output = cv2.cvtColor(output, cv2.COLOR_BGR2RGB)
        return output


    ## Filter 3 ##

    def filter3_NormalCamera(img):
        output = FunctionsMainWindow.target_normalCamera(img)
        return output


    ## Filter 4 ##

    def filter4_NormalCamera(img):
        output = np.copy(img)
        output = cv2.Laplacian(output, cv2.CV_8U)
        return output
    



    ###################################### 
    ########## OPEN FUNCTIONS ############
    ######################################


    def detect_fever(img):
        global r,g,b
        global thickness
        
        img_celsius = (img-27315)/100.0 # milli kelvin to °C
        
        output = (img-27315)/100.0 # milli kelvin to °C
        cv2.normalize(output, output, 0, 255, cv2.NORM_MINMAX)
        output = np.uint8(output)
        output = cv2.applyColorMap(output, ms.current_cv2_colormap)
        output = cv2.cvtColor(output, cv2.COLOR_BGR2RGB)
        heatmapped_img = output

        if (cv2.inRange(img_celsius,0.1,37.4).any() == True):
            range_mask = cv2.inRange(img_celsius,0.1,37.4)
            r = 152
            g = 255
            b = 51
            thickness = 4
            fever_type = ""
        if (cv2.inRange(img_celsius,37.5,38.0).any() == True):
            range_mask = cv2.inRange(img_celsius,37.5,38.0)
            r = 255
            g = 178
            b = 102
            thickness = 1
            fever_type = "SUBFEBRIL"
            
        if (cv2.inRange(img_celsius,38.1,38.5).any() == True):
            range_mask = cv2.inRange(img_celsius,38.1,38.5)
            r = 255
            g = 128
            b = 0
            thickness = 1
            fever_type = "LOW"
            
        if (cv2.inRange(img_celsius,38.5,39.0).any() == True):
            range_mask = cv2.inRange(img_celsius,38.5,39.0)
            r = 255
            g = 102
            b = 102
            thickness = 1
            fever_type = "MODERATE"

        if (cv2.inRange(img_celsius,39.1,39.9).any() == True):
            range_mask = cv2.inRange(img_celsius,39.1,39.9)
            r = 255
            g = 51
            b = 51
            thickness = 1
            fever_type = "HIGH"   
            
        if (cv2.inRange(img_celsius,40.0,42.0).any() == True):
            range_mask = cv2.inRange(img_celsius,40.0,42.0)
            r = 204
            g = 0
            b = 0
            thickness = 1
            fever_type = "VERY HIGH"                    
        
        kernal = np.ones((5,5),"uint8")
        dilated_mask = cv2.dilate(range_mask,kernal)
        
        contours,hierarchy = cv2.findContours(dilated_mask,cv2.RETR_TREE,cv2.CHAIN_APPROX_SIMPLE)
        
        for pic, contour in enumerate(contours):
            area = cv2.contourArea(contour)
            if area > 30:
                x,y,w,h = cv2.boundingRect(contour)
                heatmapped_img = cv2.rectangle(heatmapped_img,(x,y),(x+w,y+h),(r,g,b),thickness)
                cv2.putText(heatmapped_img, f"{fever_type}", (x,y),cv2.FONT_HERSHEY_SIMPLEX,0.3,(r,g,b))
        return heatmapped_img




    def detect_fever_normal_camera(img):
        global r,g,b
        global thickness
        
        img = img.astype(float)
        img_celsius = img
    
        output = img
        output = np.uint8(output)
        output = cv2.applyColorMap(output, ms.current_cv2_colormap)
        output = cv2.cvtColor(output, cv2.COLOR_BGR2RGB)
        heatmapped_img = output

        

        if (cv2.inRange(img_celsius,0.0,36.0).any() == True):
            range_mask = cv2.inRange(img_celsius,0.0,36.0)
            r = 152
            g = 255
            b = 51
            thickness = 4
            fever_type = ""

        if (cv2.inRange(img_celsius,37.0,72.0).any() == True):
            range_mask = cv2.inRange(img_celsius,37.0,72.0)
            r = 255
            g = 178
            b = 102
            thickness = 1
            fever_type = "SUB"

        if (cv2.inRange(img_celsius,73.0,108.0).any() == True):
            range_mask = cv2.inRange(img_celsius,73.0,108.0)
            r = 255
            g = 128
            b = 0
            thickness = 1
            fever_type = "LOW"
            
        if (cv2.inRange(img_celsius,109.0,144.0).any() == True):
            range_mask = cv2.inRange(img_celsius,109.0,144.0)
            r = 255
            g = 102
            b = 102
            thickness = 1
            fever_type = "MOD"

        if (cv2.inRange(img_celsius,145.0,177.0).any() == True):
            range_mask = cv2.inRange(img_celsius,145.0,177.0)
            r = 255
            g = 51
            b = 51
            thickness = 1
            fever_type = "HIGH"   
            
        if (cv2.inRange(img_celsius,178.0,213.0).any() == True):
            range_mask = cv2.inRange(img_celsius,178.0,213.0)
            r = 204
            g = 0
            b = 0
            thickness = 1
            fever_type = "VERY HIGH"
            
        if (cv2.inRange(img_celsius,214.0,255.0).any() == True):
            range_mask = cv2.inRange(img_celsius,214.0,255.0)
            r = 255
            g = 0
            b = 127
            thickness = 1
            fever_type = "LETHAL"           
        
        kernal = np.ones((5,5),"uint8")
        dilated_mask = cv2.dilate(range_mask,kernal)
        
        contours,hierarchy = cv2.findContours(dilated_mask,cv2.RETR_TREE,cv2.CHAIN_APPROX_SIMPLE)
        
        for pic, contour in enumerate(contours):
            area = cv2.contourArea(contour)
            if area > 30:
                x,y,w,h = cv2.boundingRect(contour)
                heatmapped_img = cv2.rectangle(heatmapped_img,(x,y),(x+w,y+h),(r,g,b),thickness)
                cv2.putText(heatmapped_img, f"{fever_type}", (x,y),cv2.FONT_HERSHEY_SIMPLEX,2,(r,g,b))
        return heatmapped_img

    
    def target(img):

        dim = img.shape
        height=dim[0]
        width=dim[1]
        measPoint=img[int(height/2)][int(width/2)]
        crosshairs_coord = (int(width/2), int(height/2))
        value_coord = (0, height-(int(height/10)))

        crosshairs_color = (255,255,255)
        
        cv2.normalize(img, img, 0, 255, cv2.NORM_MINMAX)
        img = np.uint8(img)
        
        
        output = img.copy()
        output = cv2.applyColorMap(output, ms.current_cv2_colormap)
        output = cv2.cvtColor(output, cv2.COLOR_BGR2RGB)

        cv2.circle(output,crosshairs_coord,ms.crosshairs_radius,crosshairs_color,ms.crosshairs_thickness)
        cv2.putText(output,f"{round(measPoint,1)}",value_coord,cv2.FONT_HERSHEY_PLAIN,ms.textsize_target,crosshairs_color,ms.textthickness_target)

        return output

    def target_normalCamera(img):

        dim = img.shape
        height=dim[0]
        width=dim[1]
        measPoint=img[int(height/2)][int(width/2)]
        crosshairs_coord = (int(width/2), int(height/2))
        value_coord = (0, height-(int(height/10)))

        crosshairs_color = (255,255,255)
            
        output = img.copy()
        output = cv2.applyColorMap(output, ms.current_cv2_colormap)
        output = cv2.cvtColor(output, cv2.COLOR_BGR2RGB)

        cv2.circle(output,crosshairs_coord,ms.crosshairs_radius,crosshairs_color,ms.crosshairs_thickness)
        cv2.putText(output,f"{round(measPoint,1)}",value_coord,cv2.FONT_HERSHEY_PLAIN,ms.textsize_target,crosshairs_color,ms.textthickness_target)

        return output


    ## Heatmap Functions ##
    
    def Apply_Scanned_Heatmap(img, blank_rgb, width, height, heatMap_array):
        # (no clipping included)
        index_matrix = blank_rgb
        index_matrix = cv2.normalize(img, img, 0, len(heatMap_array), cv2.NORM_MINMAX)
        index_matrix = index_matrix.astype(int)

        for x in range(width):
            for y in range(height):
                blank_rgb[x][y] = heatMap_array[index_matrix[x][y]-1]

        blank_rgb = np.uint8(blank_rgb)
        return blank_rgb
    
    

    def Apply_Graymap(img, minimum,maximum):
        
        dim = img.shape
        width = dim[0]
        height = dim[1]
        mini = minimum
        maxi = maximum
        miniHeatMap = 0
        maxiHeatMap = 255
        rang = maxi - mini
        unit = int(255 / rang)
        
        for i in range(width):
            for j in range(height):                                   
                factor_for_position = (abs(img[i][j] - mini))
                if img[i][j] < mini:
                    img[i][j] = miniHeatMap
                    
                elif img[i][j] > maxi:
                    img[i][j] = maxiHeatMap
                
                elif img[i][j] > mini and img[i][j] < maxi:
                    img[i][j] = int(unit) * factor_for_position
        return img
    
    


    ## Zoom ##

    def minusZoom():
        # Zoom Limiter
        if ms.currentZoomFactor - ms.zoomStep <= ms.minZoomFactor:
            ms.currentZoomFactor = ms.minZoomFactor
        else: 
            ms.currentZoomFactor = ms.currentZoomFactor - ms.zoomStep

            #tried to make cropped Image reversed
            #ms.croppedX1 = ms.croppedX1 - ms.cropUnitX
            #ms.croppedX2 = ms.croppedX2 + ms.cropUnitX
            #ms.croppedY1 = ms.croppedY1 - ms.cropUnitY
            #ms.croppedY2 = ms.croppedY2 + ms.cropUnitY

        ms.currentRes = tuple(map(mul, ms.StreamResolution, (ms.currentZoomFactor, ms.currentZoomFactor)))
        ms.currentRes = tuple(map(lambda x: int(x), ms.currentRes))

        

    def plusZoom():
        
        # Zoom Limiter
        if ms.currentZoomFactor + ms.zoomStep >= ms.maxZoomFactor:
            ms.currentZoomFactor = ms.maxZoomFactor
        else: 
            ms.currentZoomFactor = ms.currentZoomFactor + ms.zoomStep

            ## tried to calculate difference to Stream Resolution to crop Image
            #ms.croppedX1 = int((ms.currentRes[0]-ms.StreamResolution[0]) / 2)
            #ms.croppedX2 = int(ms.currentRes[0] - ((ms.currentRes[0]-ms.StreamResolution[0]) / 2))
            #ms.croppedY1 = int((ms.currentRes[1]-ms.StreamResolution[1]) / 2)
            #ms.croppedY2 = int(ms.currentRes[1] - ((ms.currentRes[1]-ms.StreamResolution[1]) / 2))

        ms.currentRes = tuple(map(mul, ms.StreamResolution, (ms.currentZoomFactor, ms.currentZoomFactor)))
        ms.currentRes = tuple(map(lambda x: int(x), ms.currentRes))

        
        
    
    def updateZoomLabel():
        ms.currentZoomDisplay = str(ms.currentZoomFactor) + 'x'
        

    ## Screenshot ##

    def takeScreenshot(img):
        output = img.copy()
        #output = output[ms.croppedY1:ms.croppedY2, ms.croppedX1:ms.croppedX2]
        output = cv2.cvtColor(output, cv2.COLOR_RGB2BGR)
        output_name = str(datetime.datetime.now().today()).replace(":", " ") + ".jpg"
        cv2.imwrite(os.path.join(ms.foto_save_path, f'{output_name}'), output)
        ms.screenshotSwitch = False

    def set_detected_min_max(img,cmapCanvas,MaximumCanvas,MiddleCanvas,MinimumCanvas):
        img = np.round(img,1)
        ms.minimum = np.min(img)
        ms.maximum = np.max(img)
        cmapCanvas.itemconfig(MaximumCanvas,text=str(ms.maximum))
        cmapCanvas.itemconfig(MinimumCanvas,text=str(ms.minimum))

        middle_temp = ms.minimum + (ms.maximum-ms.minimum) / 2
        middle_temp = np.round(middle_temp,1)
        cmapCanvas.itemconfig(MiddleCanvas,text=str(middle_temp))
        
    def set_new_cmap(cmapCanvas, CmapCanvas):
        canvas_image=ImageTk.PhotoImage(Image.open(ms.current_cmap).resize((30,ms.StreamResolution[1])))
        cmapCanvas.itemconfig(CmapCanvas,image=canvas_image)






    ## Other Functions ##

    def edgeFilterLaplace(img):
        output = np.copy(img)
        output = cv2.Laplacian(output, cv2.CV_64F)
        output = np.uint8(output)
        return output
    
    def edgeFilterCanny(img):
        output = np.copy(img)
        output = cv2.Canny(output, 100, 100)

        (B, G, R) = cv2.split(img)
        B_cny = cv2.Canny(B, 50, 200)
        G_cny = cv2.Canny(G, 50, 200)
        R_cny = cv2.Canny(R, 50, 200)
        edgeFilteredCannyRGB = cv2.merge([B_cny, G_cny, R_cny]) 
        return edgeFilteredCannyRGB

    def redFilter(img2):
        red_img = np.copy(img2)
        red_filter = (red_img[:, :, 0] > 150) & (red_img[:, :, 1] < 100) & (red_img[:, :, 2] < 110) #red filter (threshhold)
        red_img[:, :, 0] = red_img[:, :, 0] * red_filter #apllying filter
        red_img[:, :, 1] = red_img[:, :, 1] * red_filter #apllying filter
        red_img[:, :, 2] = red_img[:, :, 2] * red_filter #apllying filter
        return red_img

    def combineEdgeAndRed(imgCanny, imgRed):
        imgCanny = cv2.cvtColor(imgCanny, cv2.COLOR_BGR2GRAY)
        result = np.dstack((imgRed, imgCanny))
        return result
        
        
        """
        #imgCanny = imgCanny.convert('RGB')
        for x in imgRed:
            for y in imgRed:
                imgRed = Image.fromarray(imgRed[x,y])
                r, g, b = imgRed.getpixel((x, y))
                a = (r, g, b)
                if a != (0,0,0):
                    imgCanny[x, y] = imgRed[x,y]
                else:
                    imgCanny[x,y] = imgCanny[x,y]
                    
        return imgCanny
        """

    def testPrint():
        print('test')






    
    

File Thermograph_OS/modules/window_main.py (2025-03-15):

#-------------------------------------------------------------------#
################ Source Code written by Aaron Schultz ###############
##################### Co-Writer: Falko Kristen ######################
####### All Rights Reserved, Copyright (c) 2023 Aaron Schultz #######
#-------------------------------------------------------------------#

################ SCRIPT IMPORTS ################

## extrern library imports ##
import tkinter
import customtkinter
from PIL import Image, ImageTk
import cv2
import numpy as np
import pickle
import struct
from subprocess import call
import time


## intern module imports ##
from modules.design_states import DesignStates as ds
from modules.memory_states import MemoryStates as ms
from modules.functions_main_window import FunctionsMainWindow as fMain
from modules.window_menu import MenuWindow
from modules.window_shutdown import ShutdownWindow







############## MAIN WINDOW ################

class MainWindow(customtkinter.CTk):
    def __init__(self):
        super().__init__()
        
    

        ############## WINDOW MAIN (self) CONFIGURATIONS ################

        self.geometry(f"{ms.raspberryPieDisplayResolutionWidth}x{ms.raspberryPieDisplayResolutionHeight}")
        self.title("Thermograph Betriebssoftware")
        #self.resizable(False,False) # Turn On/Off Window Size Locked
        self.overrideredirect(ds.NoWindowBorder) # TURN ON/OFF WINDOW BORDER FOR MAIN WINDOW



        ############### GRID LAYOUT ################

        tkinter.Grid.rowconfigure(self, 0, weight=3)
        tkinter.Grid.rowconfigure(self, 1, weight=0)
        tkinter.Grid.rowconfigure(self, 2, weight=3)
        tkinter.Grid.rowconfigure(self, 3, weight=10)
        tkinter.Grid.rowconfigure(self, 4, weight=10)
        tkinter.Grid.rowconfigure(self, 5, weight=3)
        tkinter.Grid.rowconfigure(self, 6, weight=0)
        tkinter.Grid.rowconfigure(self, 7, weight=0)

        tkinter.Grid.columnconfigure(self, 0, weight=1000000)
        tkinter.Grid.columnconfigure(self, 1, weight=1)
        tkinter.Grid.columnconfigure(self, 2, weight=1)





        ################# WIDGETS MAIN ################

        ## Camera Label ##
        camLabel = tkinter.Label(self, 
                width = ms.StreamResolution[0], 
                height= ms.StreamResolution[1],
                borderwidth = 0)
        camLabel.grid(row=0, rowspan=7, column=1)
        
        def camLabelCallback(stopStreamSwitch):
            if ms.streamStopSwitch == False:
                ms.streamStopSwitch = True
            else : ms.streamStopSwitch = False
        camLabel.bind("<Button-1>", camLabelCallback)

        ## Zoom Label ##
        zoomLabel = customtkinter.CTkLabel(master=self,
                textvariable=tkinter.StringVar(value=str(ms.currentZoomFactor) + 'x'),
                text_font = ('Helvetica',8))
        zoomLabel.grid(row=1, column=0, sticky='nesw')
        
        ## Heatmap Canvas ##
        cmapCanvas = tkinter.Canvas(master=self,
                                    width = 30,
                                    height = ms.flirPureThermalCameraResolutionResized[1],
                                    bd = 0,
                                    highlightthickness=0,)
        cmapCanvas.grid(row=0,rowspan=7,column=2)

        canvas_image=ImageTk.PhotoImage(Image.open(ms.current_cmap).resize((30,ms.StreamResolution[1])))
        CmapCanvas = cmapCanvas.create_image(30, ms.StreamResolution[1], anchor='se', image=canvas_image)
        CelsiusCanvas = cmapCanvas.create_text(13,ms.StreamResolution[1]/4, anchor='center', text='°C', font=('Helvetica','10','bold'))
        MaximumCanvas = cmapCanvas.create_text(13,12, anchor='center', text=str(ms.maximum), font=('Helvetica','8'))
        middle_temp = ms.minimum + (ms.maximum-ms.minimum) / 2
        MiddleCanvas = cmapCanvas.create_text(13,ms.StreamResolution[1]/2, anchor='center', text=str(middle_temp), font=('Helvetica','8'))
        MinimumCanvas = cmapCanvas.create_text(13,ms.StreamResolution[1]-12, anchor='center', text=str(ms.minimum), font=('Helvetica','8'))

            

        ## PlusButton ##
        plusButton = customtkinter.CTkButton(master=self,
                fg_color=ds.button_fg_color,
                bg_color=ds.button_bg_color,
                hover_color=ds.button_hover_color,
                border_width=ds.button_border_width,
                border_color=ds.button_border_color,
                corner_radius=ds.button_corner_radius,
                text=ds.button_text,
                text_color=ds.button_text_color,
                image=ImageTk.PhotoImage(Image.open(ms.plus_button_path).resize((12, 12))),
                command=lambda:[fMain.plusZoom(), fMain.updateZoomLabel(), zoomLabel.configure(textvariable=tkinter.StringVar(value=ms.currentZoomDisplay))])
        plusButton.grid(row=0, column=0, sticky='nesw')

        ## Minus Button ##
        minusButton = customtkinter.CTkButton(master=self,
                fg_color=ds.button_fg_color,
                bg_color=ds.button_bg_color,
                hover_color=ds.button_hover_color,
                border_width=ds.button_border_width,
                border_color=ds.button_border_color,
                corner_radius=ds.button_corner_radius,
                text=ds.button_text,
                text_color=ds.button_text_color,
                image=ImageTk.PhotoImage(Image.open(ms.minus_button_path).resize((12, 12))),
                command=lambda:[fMain.minusZoom(), fMain.updateZoomLabel(), zoomLabel.configure(textvariable=tkinter.StringVar(value=ms.currentZoomDisplay))])
        minusButton.grid(row=2, column=0, sticky='nesw')

        ## Screenshot Button ##
        screenShotButton = customtkinter.CTkButton(master=self,
                fg_color=ds.button_fg_color,
                bg_color=ds.button_bg_color,
                hover_color=ds.button_hover_color,
                border_width=ds.button_border_width,
                border_color=ds.button_border_color,
                corner_radius=ds.button_corner_radius,
                text=ds.button_text,
                text_color=ds.button_text_color,
                image=ImageTk.PhotoImage(Image.open(ms.screenshot_button_path).resize((16, 16))),
                command= fMain.changeScreenshotSwitch)
        screenShotButton.grid(row=3, column=0, sticky='nesw')
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

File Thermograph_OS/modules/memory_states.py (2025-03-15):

#-------------------------------------------------------------------#
################ Source Code written by Aaron Schultz ###############
##################### Co-Writer: Falko Kristen ######################
####### All Rights Reserved, Copyright (c) 2023 Aaron Schultz #######
#-------------------------------------------------------------------#

################ SCRIPT IMPORTS ################

## extrern library imports ##
import cv2
import platform
import pickle
import socket
import struct
import numpy as np
from subprocess import call
import time




################ GLOBAL MEMORY STATES ################

class MemoryStates:

    def heatmap_setup(current_cmap, maximum, minimum):

        ## Loading PNG file as Heat Map
        color_arr = cv2.imread(current_cmap)
        color_arr = cv2.cvtColor(color_arr, cv2.COLOR_BGR2RGB)

        ## Analyzing Heat Map PNG and storing in array
        cmap_dim = color_arr.shape
        cmap_height = cmap_dim[0]
        cmap_width = cmap_dim[1]
        counter = 0
        heatMap_array = []
        while counter < cmap_height:
            for i in range(cmap_height):
                for j in range(1):
                    r = color_arr[i][1][0]
                    g = color_arr[i][1][1]
                    b = color_arr[i][1][2]
                    rgb_val = (r,g,b)
                    heatMap_array.append(rgb_val)
                    counter +=1

        ## reverses Heat Map Image
        heatMap_array = heatMap_array[::-1]
        temp_range = maximum - minimum

        temp_unit_range = maximum - minimum
        temp_unit=int(len(heatMap_array)/temp_unit_range)

        return heatMap_array, temp_unit, temp_range




    ## Setup Platform and Sensor ##
    OS = str(platform.system())
    print('OS: ' + OS)


    if OS == 'Windows':
        try:
            cameraInputNumber = 10
            for i in reversed(range(cameraInputNumber+1)):
                cap = cv2.VideoCapture(i)
                if cap.isOpened():
                    cameraInputNumber = i
                    print("Camera Input found: ", cameraInputNumber)
                    Sensor = 'Normal_Camera'
                    break
        except: print('Normal Camera could not be set up on ' + OS)

    elif OS == 'Darwin':
        try:
            cameraInputNumber = 10
            for i in reversed(range(cameraInputNumber+1)):
                cap = cv2.VideoCapture(i)
                if cap.isOpened():
                    cameraInputNumber = i
                    print("Camera Input found: ", cameraInputNumber)
                    Sensor = 'Normal_Camera'
                    break
        except: print('Normal Camera could not be set up on macOS')
    
    elif OS == 'Linux':
        try:
            import board,busio #available only for Linux
            import adafruit_mlx90640 #available only for Linux
            i2c = busio.I2C(board.SCL, board.SDA, frequency=800000) # I2C Setup
            mlx = adafruit_mlx90640.MLX90640(i2c) # begin communication MLX90640 with I2C
            Sensor = 'MLX'
        except:
            Sensor = 'Error'
            print('MLX Sensor could not be found.')
        try:
            cameraInputNumber = 10
            for i in reversed(range(cameraInputNumber+1)):
                cap = cv2.VideoCapture(i)
                if cap.isOpened():
                    cameraInputNumber = i
                    print("Camera Input found: ", cameraInputNumber)
                    Sensor = 'Flir'
                    break
        except: print('Flir Sensor could not be set up on ' + OS)

    else: 
        print('No known operating system was detected')
        OS = 'Error'
        Sensor = 'Error'
    print('Sensor: ' + Sensor)




    ## Resolution Variables ##

    flirPureThermalCameraResolution = (160, 120)
    flirResizeFactor = 2.65
    flirPureThermalCameraResolutionResized = tuple(2.65 * i for i in flirPureThermalCameraResolution)
    flirPureThermalCameraResolutionResized = tuple(map(lambda x: int(x), flirPureThermalCameraResolutionResized))

    mlxCameraResolution = (24,32)

    if OS == 'Windows' or OS == 'Darwin':
        cap = cv2.VideoCapture(cameraInputNumber)
        ret, img = cap.read()
        cameraHeight, cameraWidth, channel = img.shape
        originalCameraResolution = (cameraWidth, cameraHeight)
    elif OS == 'Linux':
        if Sensor == 'MLX':
            originalCameraResolution = mlxCameraResolution
        elif Sensor == 'Flir':
            originalCameraResolution = flirPureThermalCameraResolutionResized
        else: originalCameraResolution = flirPureThermalCameraResolutionResized
    else: print('No Resolution could be set up.')
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
